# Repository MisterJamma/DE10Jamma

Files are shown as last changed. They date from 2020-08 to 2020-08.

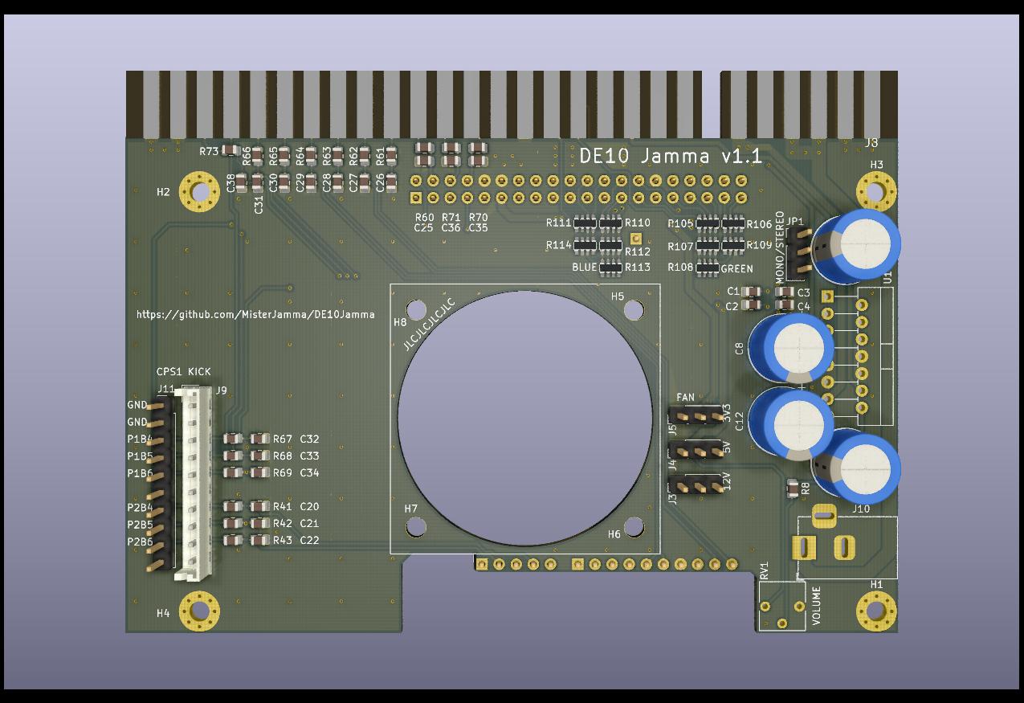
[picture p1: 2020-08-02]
DE10Jamma.jpg

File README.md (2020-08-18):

# DE10Jamma

JAMMA/NeoGeo MVS audio, video & control IO for DE10-Nano.

[https://github.com/MisterJamma/DE10Jamma](https://github.com/MisterJamma/DE10Jamma)

Discussion thread: [https://www.atari-forum.com/viewtopic.php?f=120&t=38793](https://www.atari-forum.com/viewtopic.php?f=120&t=38793)

Imgur

## Description

### Overview
DE10Jamma allows a DE10-Nano board to be connected directly to an arcade cabinet as simply as possible. USB and HDMI serial interfaces are not used, in order to remain as close as possible to the original arcade hardware and avoid unnecessary cost or complexity.

Pull-down resistors on AUDIO_L and AUDIO_R pins allow this board to be detected and coexist with other MiSTer hardware using common rbf files for the cores. See [this commit](https://github.com/MisterJamma/Arcade-GnG_MiSTer/commit/6c7786a7f790a5277f337f6b245e99f6ca4c25ff).

##### Future Developments
Future developments in RTL and software to more fully support DE10Jamma

1. Allow player controls to be used in the OSD.

### Inputs
Inputs are [RC filtered](https://wiki.neogeodev.org/index.php?title=CRE401) to give EMI protection to the FPGA.

No multiplexing, polling or debouncing of the inputs ensures **zero** additional latency & jitter. Cabinet switches are presented to arcade cores exactly as they would be on a real arcade PCB. Arcade cores will include necessary debouncing either in replicated hardware of the original PCB, or in software running on that hardware. When buttons are passed to the ARM host CPU for controlling the UI & selecting arcade cores, the inputs should debounced appropriately in hardware or software.

### Audio Output
2 pole RC filters convert PWM output from DE10-Nano to analog signal. Mono/Stereo jumper JP1 allows stereo signal for MVS wired cabinets, or mono signal for JAMMA wired cabinets. With no jumper fitted, there will be no audio output for the left channel.

2 channel power amplifier drives the speaker loads.

### Video Output
Composite sync is generated by DE10-Nano.

Three 6bit R-2R DACs convert the digital output from DE10-Nano to analog RGB. A single 2R value used in parallel to generate the R value with tighter tolerance. Part-to-part tolerance is typically significantly better than absolute part tolerance, so using a single 2R value for all resistors in the DAC should improve linearity.

No additional latency or incompatibility from HDMI logic and low quality HDMI converters. Resistive DACs are commonly used on arcade PCBs, and allow the original odd resolutions & refresh rates to be supported correctly. Output level is not noticeably lower than a NeoGeo MVS, and well within adjustment range on arcade monitors.

### DC Power Output
DC power output is provided for the DE10-Nano. This should be connected using a short [2.1mm male-male cable](https://www.google.com/search?q=2.1mm+male+to+male&tbm=isch), such as used to connect guitar effects pedals to a power supply.

Arcade power supplies are typically adjustable. DE10-Nano has regulation for lower voltage supplies, and should operate correctly from nominal +5v settings. If +5v rail is adjusted too high, the DE10-Nano's over-voltage protection circuitry will not allow the board to power up.

## Parts List
Qty | Reference(s)         | Value          | Part Number
----|----------------------|----------------|------------
30  | C1, C2, C3, C4, C13, C14, C15, C16, C17, C18, C19, C20, C21, C22, C23, C24, C25, C26, C27, C28, C29, C30, C31, C32, C33, C34, C35, C36, C37, C38 | 10nF | C83170
4   | C5, C6, C7, C11      | 470nF          | C106843
4   | C8, C9, C10, C12     | 1000uF         | C442834
1   | J1, J2, J6           | Long 0.1" pins | C51353
1   | JP1, J3, J4, J5, J11 | 0.1" pins      | C358690
1   | J9                   | 2.5mm JST pins | C160365
1   | J7                   | 0.1" socket    | C35165
1   | J10                  | 2.1mm power    | C319099
1   | R1                   | 100R           | C105577
28  | R2, R3, R34, R35, R36, R37, R38, R39, R40, R41, R42, R43, R44, R45, R60, R61, R62, R63, R64, R65, R66, R67, R68, R69, R70, R71, R72, R73 | 1k | C140870
16  | R4, R100, R101, R102, R103, R104, R105, R106, R107, R108, R109, R110, R111, R112, R113, R114 | 604R | Bourns CAY16-6040F4LF
1   | R8                   | 300k           | C114530
1   | RV1                  | 50k            | C81264
1   | U1                   | TDA7496        | TDA7496
1   | FAN                  | 40mm fan 5/12v | 

###### Notes
   1. Part numbers from [LSSC](https://lcsc.com/) are provided where possible. Values for some components do not match the schematic, and have been adjusted to reduce the number of different components.

   1. J1, J2 and J6 should be inserted into PCB from above, using DE10-Nano to set correct depth. Solder carefully from above & trim to length. Pins should protrude approximately 0.25" from the PCB

   1. J9 is only required for cabinets with 2.5mm pitch JST kick harness connector. It may also be possible to use 0.1" pitch J11 connector with existing kick harness, as the difference in pitch is minimal for a 10way connector.

   1. A 20mm deep fan running on a lower voltage is recommended for reduced noise.

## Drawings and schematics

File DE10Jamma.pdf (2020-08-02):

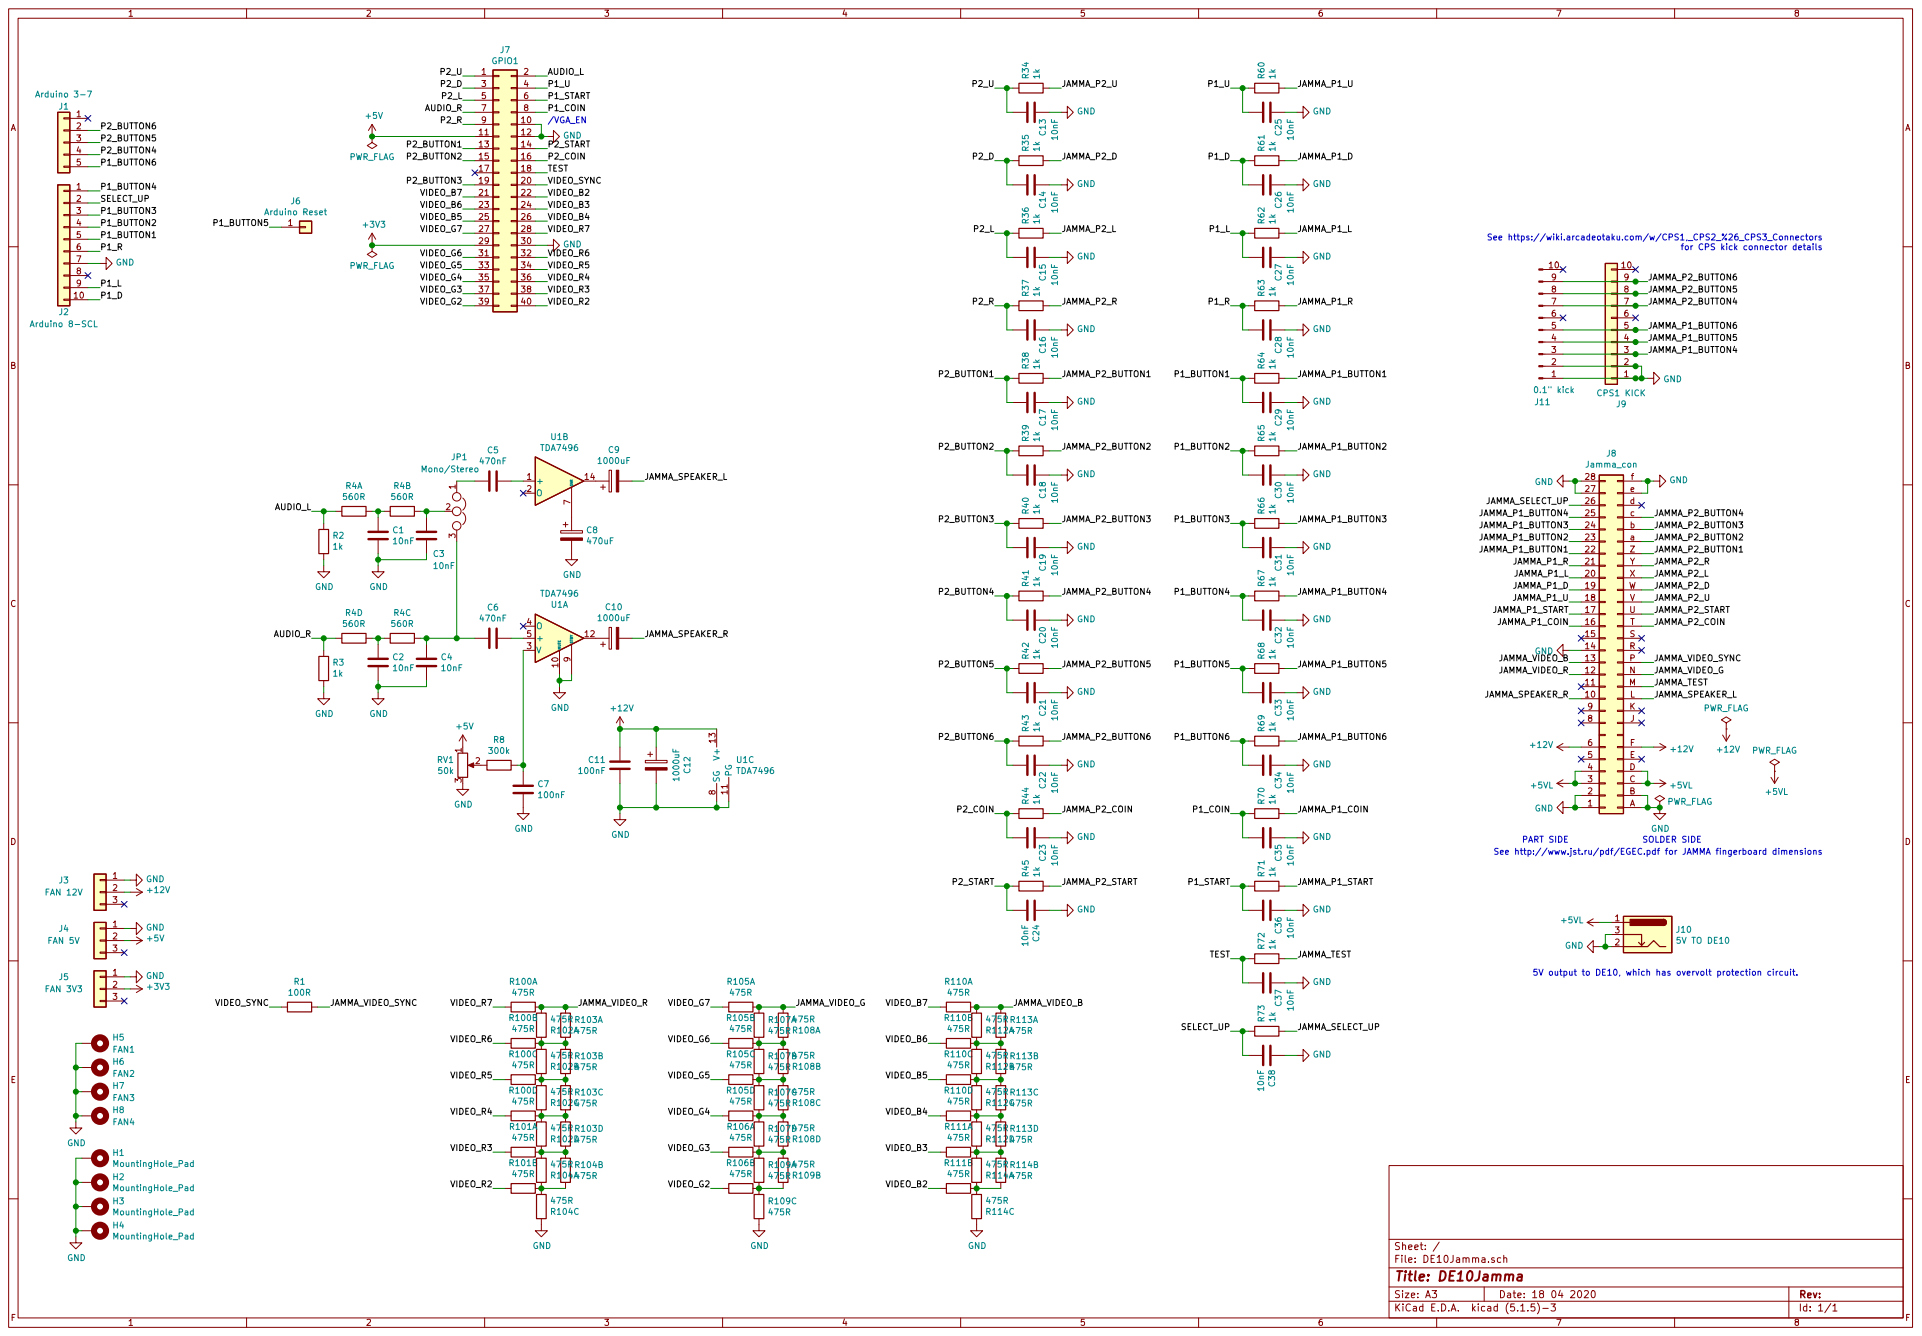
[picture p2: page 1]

See https://wiki.arcadeotaku.com/w/CPS1,_CPS2_%26_CPS3_Connectors

for CPS kick connector details

See http://www.jst.ru/pdf/EGEC.pdf for JAMMA fingerboard dimensions

5V output to DE10, which has overvolt protection circuit.

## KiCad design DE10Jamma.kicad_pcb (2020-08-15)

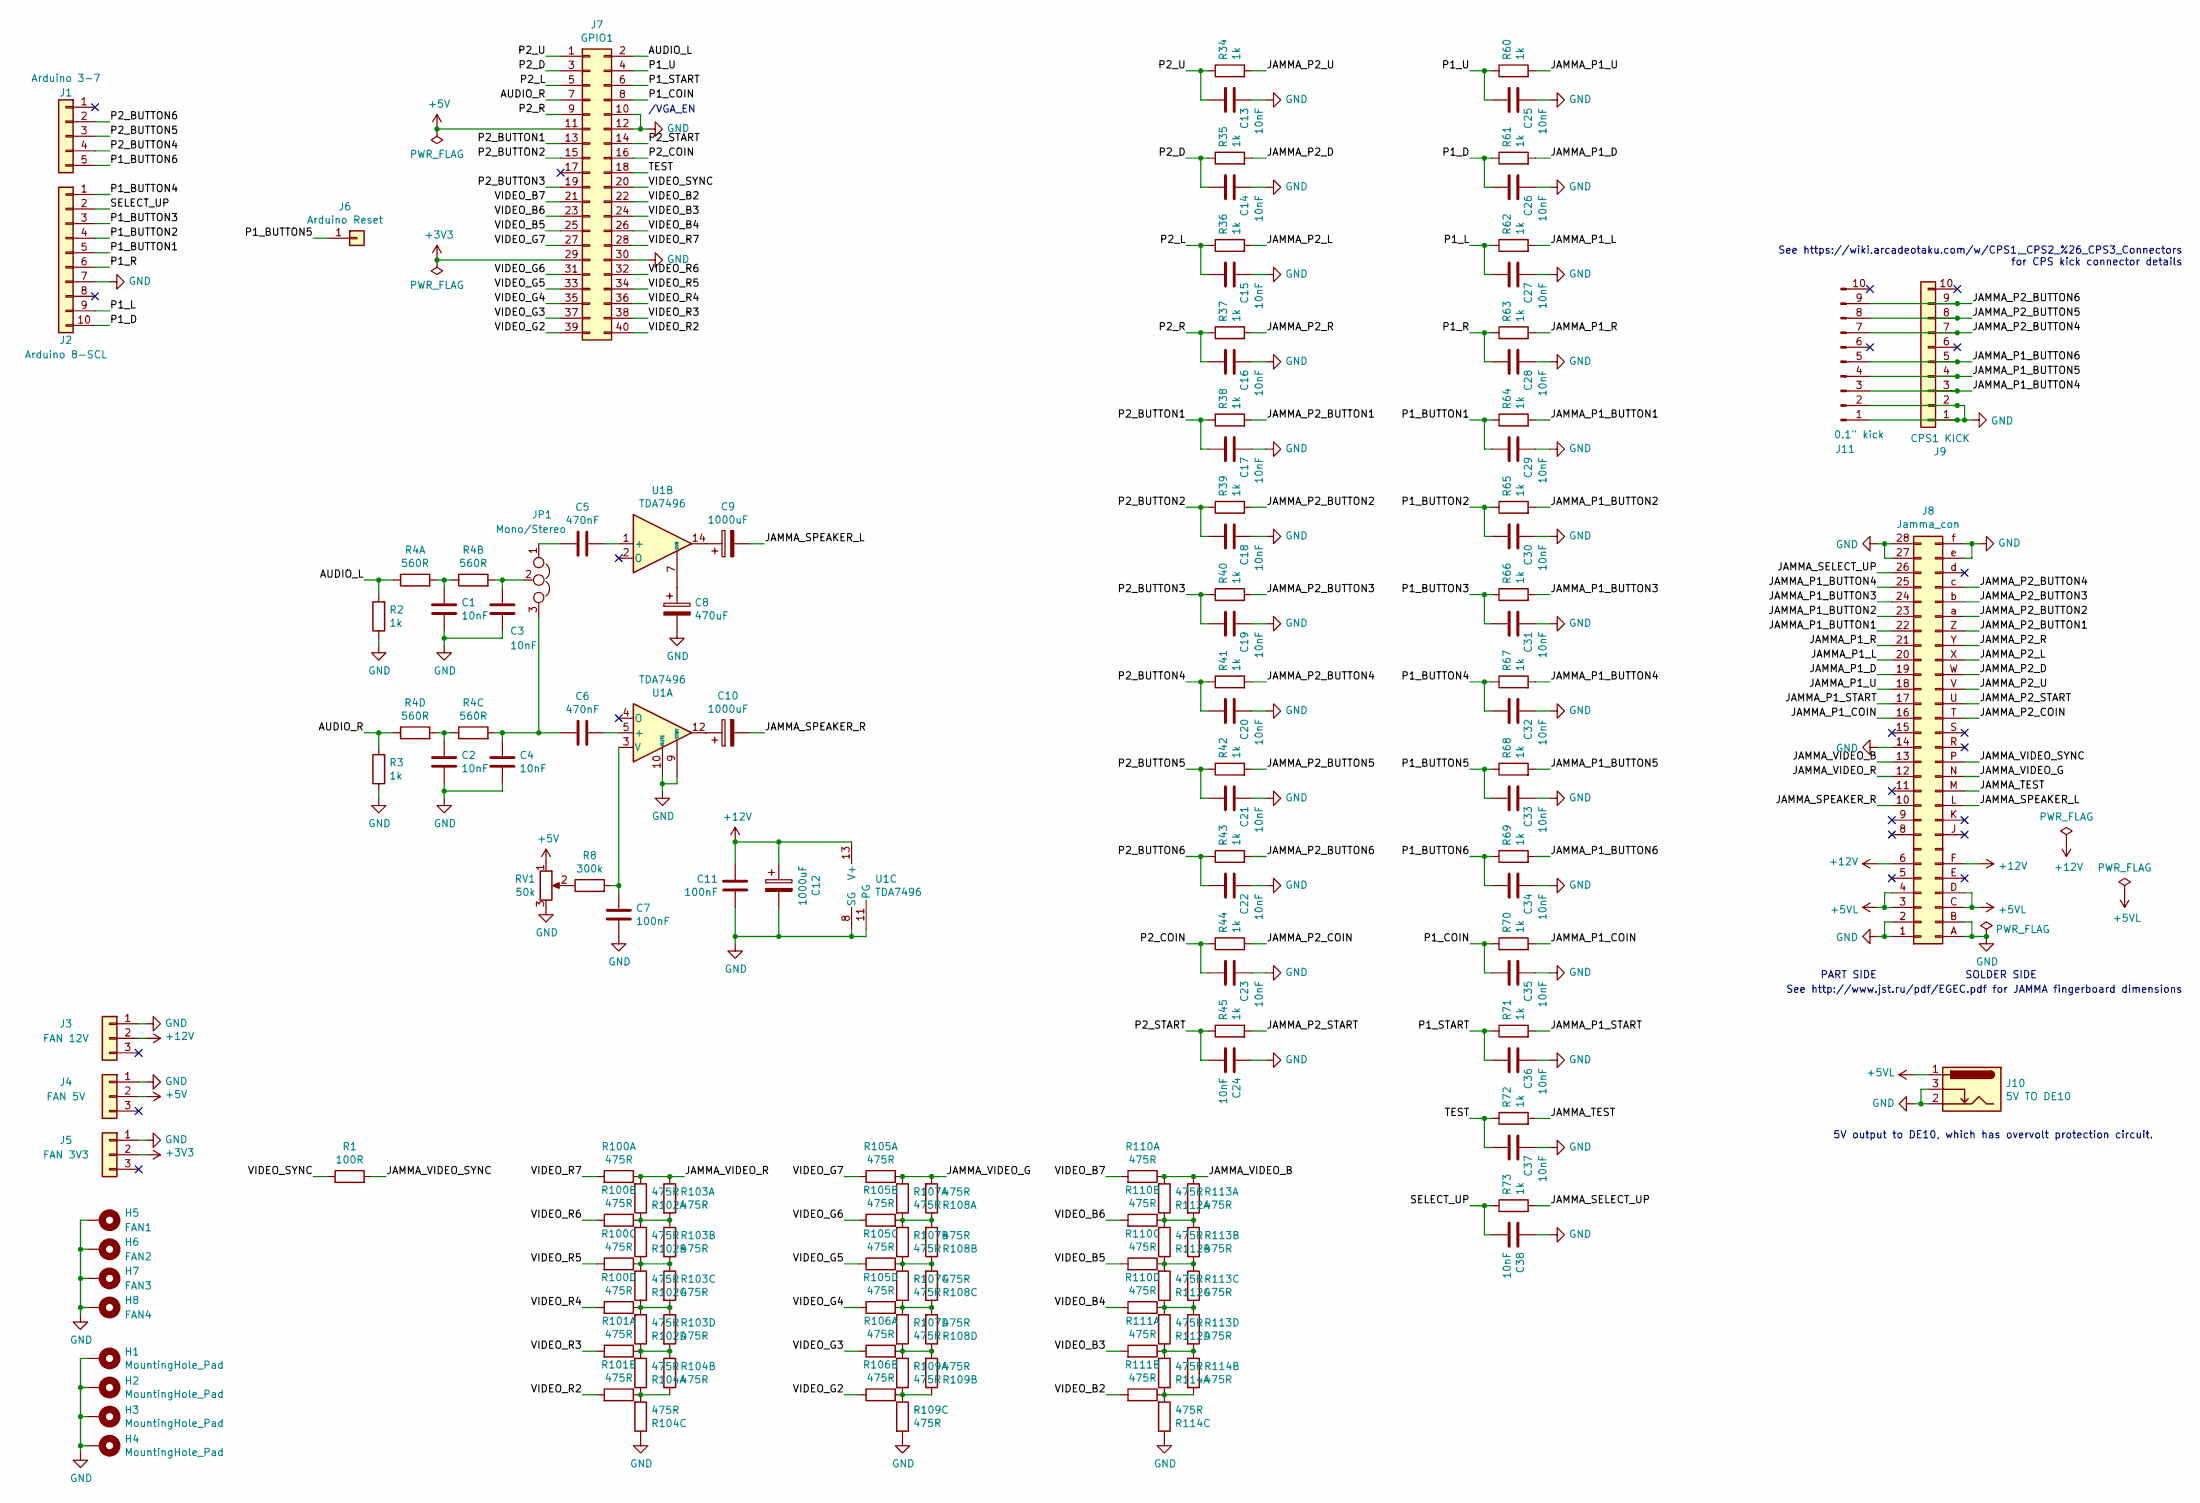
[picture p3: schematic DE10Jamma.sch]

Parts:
C1, C2, C3, C4, C13, C14, C15, C16, C17, C18, C19, C20, C21, C22, C23, C24, C25, C26, C27, C28, C29, C30, C31, C32, C33, C34, C35, C36, C37, C38: 10nF; C_0805_2012Metric
C5, C6: 470nF; C_0805_2012Metric
C7, C11: 100nF; C_0805_2012Metric
C8: 470uF; CP_Radial_D10.0mm_P5.00mm
C9, C10, C12: 1000uF; CP_Radial_D10.0mm_P5.00mm
H1, H2, H3, H4: MountingHole_Pad; MountingHole_3mm_Pad_Via
H5: FAN1; MountingHole_3mm
H6: FAN2; MountingHole_3mm
H7: FAN3; MountingHole_3mm
H8: FAN4; MountingHole_3mm
J1: Arduino 3-7; PinHeader_1x05_P2.54mm_Vertical
J2: Arduino 8-SCL; PinHeader_1x10_P2.54mm_Vertical
J3: FAN 12V; PinHeader_1x03_P2.54mm_Vertical
J4: FAN 5V; PinHeader_1x03_P2.54mm_Vertical
J5: FAN 3V3; PinHeader_1x03_P2.54mm_Vertical
J6: Arduino Reset; PinHeader_1x01_P2.54mm_Vertical
J7: GPIO1; PinSocket_2x20_P2.54mm_Vertical
J8: Jamma_con; JAMMA-56
J9: CPS1 KICK; JST_EH_B10B-EH-A_1x10_P2.50mm_Vertical
J10: 5V TO DE10; BarrelJack_Horizontal
J11: 0.1\" kick; PinHeader_1x10_P2.54mm_Vertical
JP1: Mono/Stereo; PinHeader_1x03_P2.54mm_Vertical
R1: 100R; C_0805_2012Metric
R2, R3, R34, R35, R36, R37, R38, R39, R40, R41, R42, R43, R44, R45, R60, R61, R62, R63, R64, R65, R66, R67, R68, R69, R70, R71, R72, R73: 1k; C_0805_2012Metric
R4: 560R; R_Array_Convex_4x0603
R8: 300k; C_0805_2012Metric
R100, R101, R102, R103, R104, R105, R106, R107, R108, R109, R110, R111, R112, R113, R114: 475R; R_Array_Convex_4x0603
RV1: 50k; Potentiometer_Vishay_T73YP_Vertical
U1: TDA7496; TO-220-15_P2.54x2.54mm_StaggerOdd_Lead4.58mm_Vertical

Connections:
+3V3: J5.2, J7.29
+5V: J4.2, J7.11, RV1.1
+5VL: J8.3 (+5V), J8.4 (+5V), J8.C (+5V), J8.D (+5V), J10.1
+12V: C11.1, C12.1, J3.2, J8.6 (+12V), J8.F (+12V), U1.13 (V+)
/AUDIO_L: J7.2, R2.2, R4.8
/AUDIO_R: J7.7, R3.2, R4.5
/JAMMA_P1_BUTTON1: J8.22 (P1_BUTTON_1), R64.2
/JAMMA_P1_BUTTON2: J8.23 (P1_BUTTON_2), R65.2
/JAMMA_P1_BUTTON3: J8.24 (P1_BUTTON_3), R66.2
/JAMMA_P1_BUTTON4: J8.25 (P1_BUTTON_4), J9.3, J11.3, R67.2
/JAMMA_P1_BUTTON5: J9.4, J11.4, R68.2
/JAMMA_P1_BUTTON6: J9.5, J11.5, R69.2
/JAMMA_P1_COIN: J8.16 (COIN_1), R70.2
/JAMMA_P1_D: J8.19 (P1_DOWN), R61.2
/JAMMA_P1_L: J8.20 (P1_LEFT), R62.2
/JAMMA_P1_R: J8.21 (P1_RIGHT), R63.2
/JAMMA_P1_START: J8.17 (START_1), R71.2
/JAMMA_P1_U: J8.18 (P1_UP), R60.2
/JAMMA_P2_BUTTON1: J8.Z (P2_BUTTON_1), R38.2
/JAMMA_P2_BUTTON2: J8.a (P2_BUTTON_2), R39.2
/JAMMA_P2_BUTTON3: J8.b (P2_BUTTON_3), R40.2
/JAMMA_P2_BUTTON4: J8.c (P2_BUTTON_4), J9.7, J11.7, R41.2
/JAMMA_P2_BUTTON5: J9.8, J11.8, R42.2
/JAMMA_P2_BUTTON6: J9.9, J11.9, R43.2
/JAMMA_P2_COIN: J8.T (COIN_2), R44.2
/JAMMA_P2_D: J8.W (P2_DOWN), R35.2
/JAMMA_P2_L: J8.X (P2_LEFT), R36.2
/JAMMA_P2_R: J8.Y (P2_RIGHT), R37.2
/JAMMA_P2_START: J8.U (START_2), R45.2
/JAMMA_P2_U: J8.V (P2_UP), R34.2
/JAMMA_SELECT_UP: J8.26 (SELECT_UP), R73.2
/JAMMA_SPEAKER_L: C9.2, J8.L (SPEAKER-)
/JAMMA_SPEAKER_R: C10.2, J8.10 (SPEAKER+)
/JAMMA_TEST: J8.M (TEST), R72.2
/JAMMA_VIDEO_B: J8.13 (VIDEO_BLUE), R110.8, R112.1, R113.8
/JAMMA_VIDEO_G: J8.N (VIDEO_GREEN), R105.1, R107.8, R108.1
/JAMMA_VIDEO_R: J8.12 (VIDEO_RED), R100.8, R102.1, R103.8
/JAMMA_VIDEO_SYNC: J8.P (VIDEO_SYNC), R1.2
/P1_BUTTON1: C29.2, J2.5, R64.1
/P1_BUTTON2: C30.2, J2.4, R65.1
/P1_BUTTON3: C31.2, J2.3, R66.1
/P1_BUTTON4: C32.2, J2.1, R67.1
/P1_BUTTON5: C33.2, J6.1, R68.1
/P1_BUTTON6: C34.2, J1.5, R69.1
/P1_COIN: C35.2, J7.8, R70.1
/P1_D: C26.2, J2.10, R61.1
/P1_L: C27.2, J2.9, R62.1
/P1_R: C28.2, J2.6, R63.1
/P1_START: C36.2, J7.6, R71.1
/P1_U: C25.2, J7.4, R60.1
/P2_BUTTON1: C17.2, J7.13, R38.1
/P2_BUTTON2: C18.2, J7.15, R39.1
/P2_BUTTON3: C19.2, J7.19, R40.1
/P2_BUTTON4: C20.2, J1.4, R41.1
/P2_BUTTON5: C21.2, J1.3, R42.1
/P2_BUTTON6: C22.2, J1.2, R43.1
/P2_COIN: C23.2, J7.16, R44.1
/P2_D: C14.2, J7.3, R35.1
/P2_L: C15.2, J7.5, R36.1
/P2_R: C16.2, J7.9, R37.1
/P2_START: C24.2, J7.14, R45.1
/P2_U: C13.2, J7.1, R34.1
/SELECT_UP: C38.2, J2.2, R73.1
/TEST: C37.2, J7.18, R72.1
/VIDEO_B2: J7.22, R111.2
/VIDEO_B3: J7.24, R111.1
/VIDEO_B4: J7.26, R110.4
/VIDEO_B5: J7.25, R110.3
/VIDEO_B6: J7.23, R110.2
/VIDEO_B7: J7.21, R110.1
/VIDEO_G2: J7.39, R106.7
/VIDEO_G3: J7.37, R106.8
/VIDEO_G4: J7.35, R105.5
/VIDEO_G5: J7.33, R105.6
/VIDEO_G6: J7.31, R105.7
/VIDEO_G7: J7.27, R105.8
/VIDEO_R2: J7.40, R101.2
/VIDEO_R3: J7.38, R101.1
/VIDEO_R4: J7.36, R100.4
/VIDEO_R5: J7.34, R100.3
/VIDEO_R6: J7.32, R100.2
/VIDEO_R7: J7.28, R100.1
/VIDEO_SYNC: J7.20, R1.1
GND: C1.2, C2.2, C3.2, C4.2, C7.2, C8.2, C11.2, C12.2, C13.1, C14.1, C15.1, C16.1, C17.1, C18.1, C19.1, C20.1, C21.1, C22.1, C23.1, C24.1, C25.1, C26.1, C27.1, C28.1, C29.1, C30.1, C31.1, C32.1, C33.1, C34.1, C35.1, C36.1, C37.1, C38.1, H1.1, H2.1, H3.1, H4.1, H5.1, H6.1, H7.1, H8.1, J2.7, J3.1, J4.1, J5.1, J7.10, J7.12, J7.30, J8.1 (GND), J8.2 (GND), J8.14 (VIDEO_GND), J8.27 (GND), J8.28 (GND), J8.A (GND), J8.B (GND), J8.e (GND), J8.f (GND), J9.1, J9.2, J10.2, J10.3, J11.1, J11.2, R2.1, R3.1, R104.6, R109.3, R114.6, RV1.3, U1.8 (SG), U1.9 (STBY), U1.10 (MUTE), U1.11 (PG), U1.15 (PG)
unnamed: C1.1, R4.1, R4.7
unnamed: C2.1, R4.4, R4.6
unnamed: C3.1, JP1.2, R4.2
unnamed: C4.1, C6.1, JP1.3, R4.3
unnamed: C5.1, JP1.1
unnamed: C5.2, U1.1 (+)
unnamed: C6.2, U1.5 (+)
unnamed: C7.1, R8.2, U1.3 (V)
unnamed: C8.1, U1.7 (SVR)
unnamed: C9.1, U1.14
unnamed: C10.1, U1.12
unnamed: R8.1, RV1.2
unnamed: R100.5, R102.4, R102.6, R103.3, R103.5
unnamed: R100.6, R102.3, R102.7, R103.2, R103.6
unnamed: R100.7, R102.2, R102.8, R103.1, R103.7
unnamed: R101.7, R104.2, R104.3, R104.8
unnamed: R101.8, R102.5, R103.4, R104.1, R104.7
unnamed: R105.2, R107.1, R107.7, R108.2, R108.8
unnamed: R105.3, R107.2, R107.6, R108.3, R108.7
unnamed: R105.4, R107.3, R107.5, R108.4, R108.6
unnamed: R106.1, R107.4, R108.5, R109.2, R109.8
unnamed: R106.2, R109.1, R109.6, R109.7
unnamed: R110.5, R112.4, R112.6, R113.3, R113.5
unnamed: R110.6, R112.3, R112.7, R113.2, R113.6
unnamed: R110.7, R112.2, R112.8, R113.1, R113.7
unnamed: R111.7, R114.2, R114.3, R114.8
unnamed: R111.8, R112.5, R113.4, R114.1, R114.7

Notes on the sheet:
PART SIDE
SOLDER SIDE
/VGA_EN
5V output to DE10, which has overvolt protection circuit.
See http://www.jst.ru/pdf/EGEC.pdf for JAMMA fingerboard dimensions
See https://wiki.arcadeotaku.com/w/CPS1,_CPS2_%26_CPS3_Connectors for CPS kick connector details

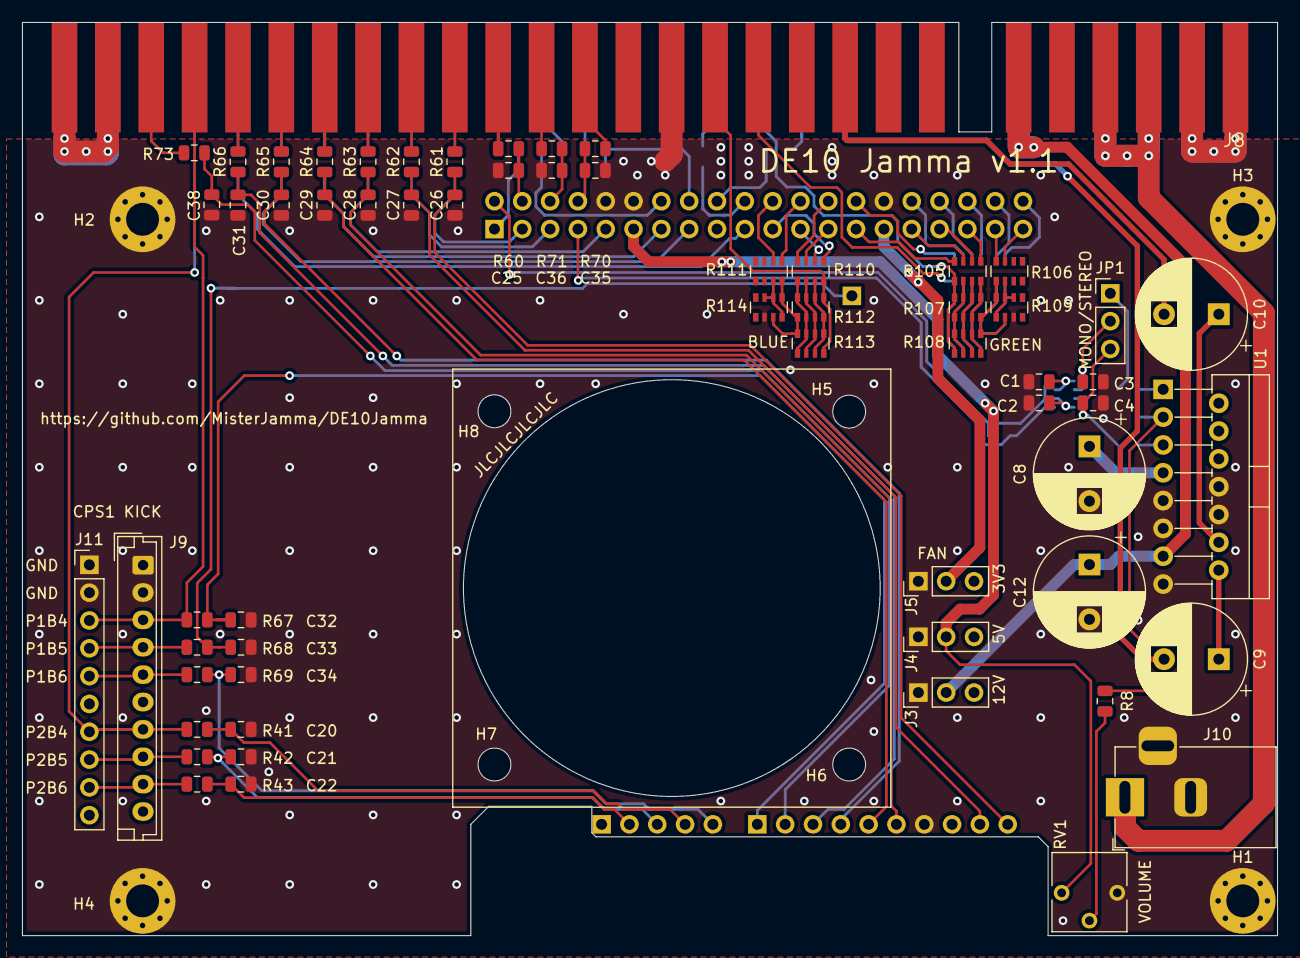
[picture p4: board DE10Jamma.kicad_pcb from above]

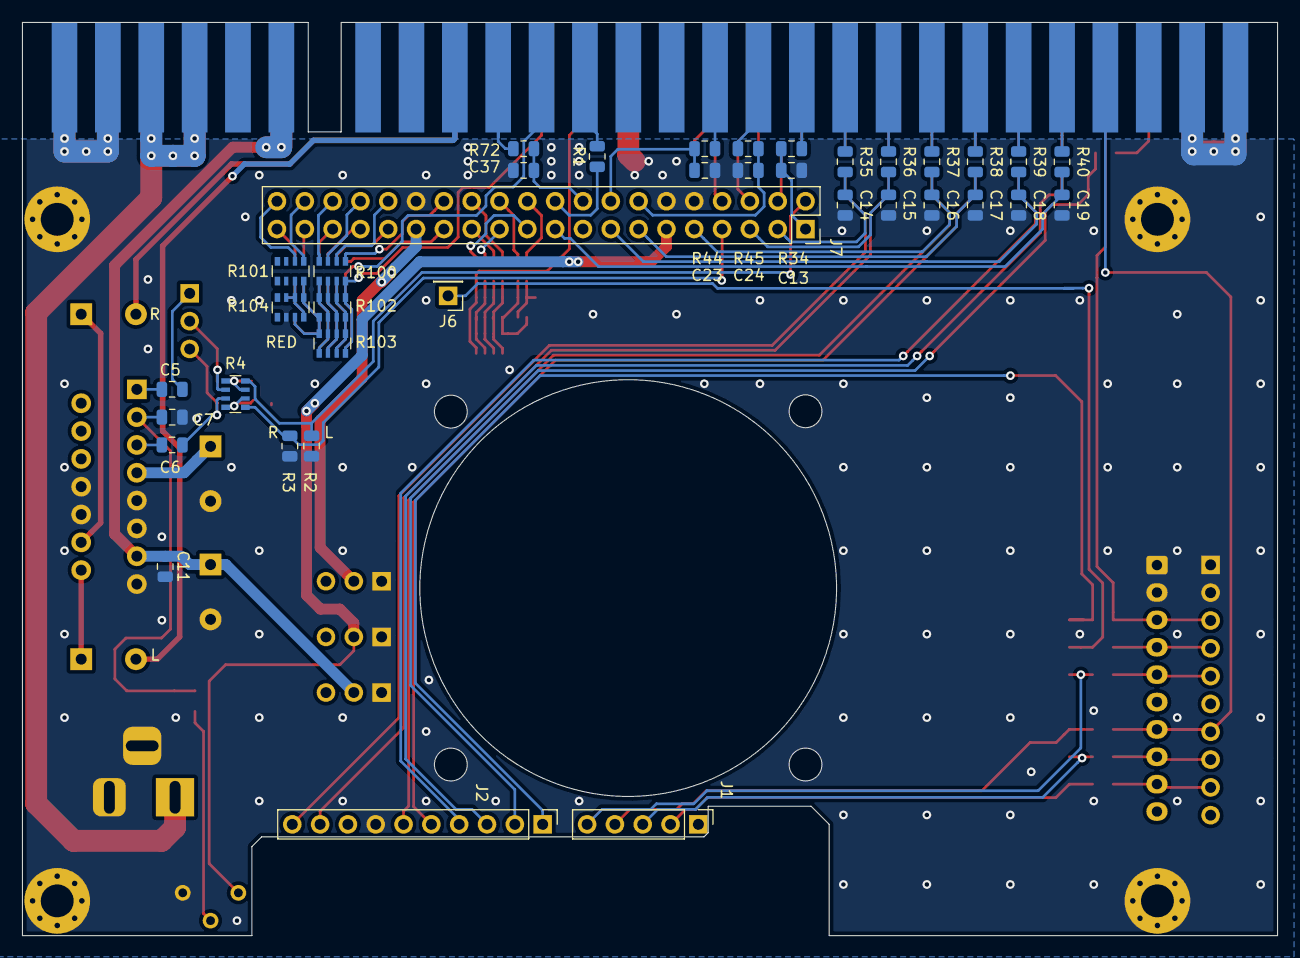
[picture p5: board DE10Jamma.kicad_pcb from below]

Board: 2 copper layers, 114.6 x 83.4 mm, 106 parts (37 on the bottom side), 111 nets.

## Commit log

2020-05-03 pdf of schematic
2020-07-05 clean before sending to manufacture
    [DE10Jamma.kicad_pcb, DE10Jamma.sch]
2020-07-05 Add mono/stereo jumper. Remove out of date pdf
    [DE10Jamma.kicad_pcb, DE10Jamma.sch]
2020-08-02 Use smaller footprint for r-packs. Rework mono/stereo jumper to avoid potential DC path issues if inputs have DC offset. General routing & silk screen cleanup.
    [DE10Jamma.kicad_pcb, DE10Jamma.sch]
2020-08-15 Route wire into JAMMA _VIDEO_G pad properly
    [DE10Jamma.kicad_pcb]
2020-08-16 Update pic & status of IO Board compatibility
2020-08-18 Add link to forum thread
